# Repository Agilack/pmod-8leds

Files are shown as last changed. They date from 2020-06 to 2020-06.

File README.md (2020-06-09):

PMOD 8 Leds
===========

This project is a PMOD prototyping board with 8 LEDs.



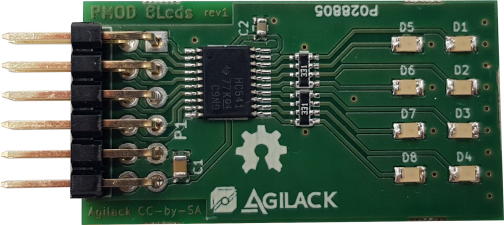
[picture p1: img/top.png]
top
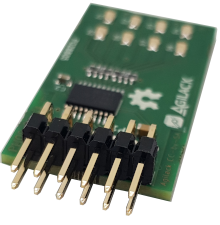
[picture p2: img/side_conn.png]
Side view
 | 
------------------- | -------------------------------

The board connector use a PMOD type 1A pinout. Each available GPIO is
connected to one LED with a component id that reflect signel id (LED D1 is
mapped to signal GPIO1, D2 for GPIO2 ...)
To avoid driving too much current from host ios, a buffer is placed between
connector and LEDs. This buffer add a small latency (~5ns) and limit the
switching frequency to fwe dozen MHz but this seem to be acceptable for
LEDs ;)

<p align="center">
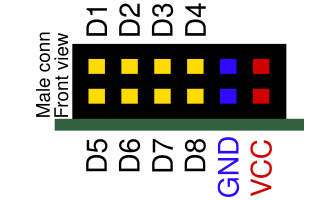
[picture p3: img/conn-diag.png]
Connector diagram

</p>

Designed with Kicad
-------------------
This board has been designed using Kicad 5.0.2
For a better compatibility and a simplified distribution of this project,
all schematics components are available into a custom project library. It's
the same for board footprints that have been saved into a cutom library. For
3D models, default kicad parts are used (and some display errors can occurs)

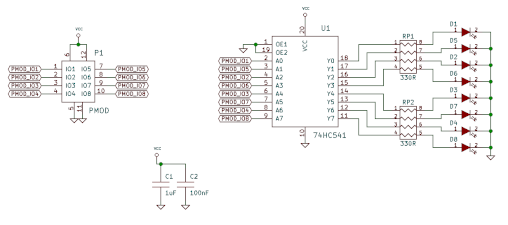
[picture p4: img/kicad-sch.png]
SCH
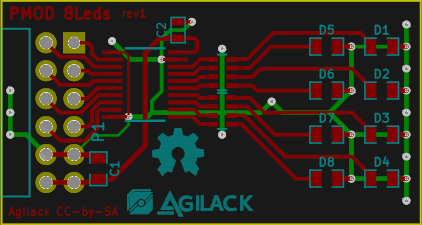
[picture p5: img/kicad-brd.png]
BRD
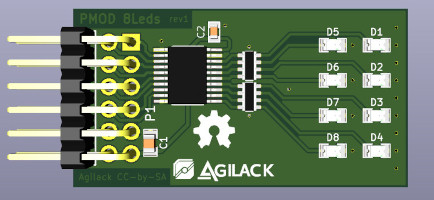
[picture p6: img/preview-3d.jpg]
3D Preview
 |  | 
------------------------- | ------------------------- | ---------------------------------

License
-------

This project is licensed under a [Creative Commons Attribution-ShareAlike 4.0 International License](http://creativecommons.org/licenses/by-sa/4.0/).



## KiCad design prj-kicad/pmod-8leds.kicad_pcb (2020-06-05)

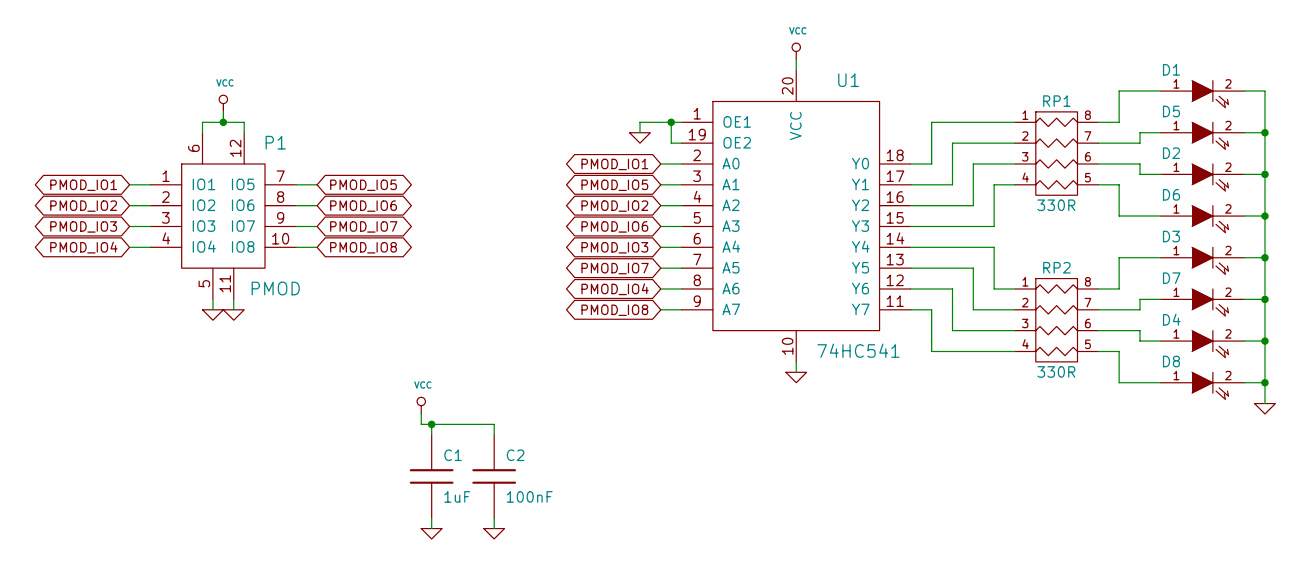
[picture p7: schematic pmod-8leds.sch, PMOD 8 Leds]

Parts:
C1: 1uF; SMD0805
C2: 100nF; SMD0603
D1, D2, D3, D4, D5, D6, D7, D8: LED; SMD0805
P1: PMOD; CONN_PMOD-Male
RP1, RP2: 330R; R_4x0603
U1: 74HC541; TSSOP20

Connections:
GND: C1.2, C2.2, D1.2 (K), D2.2 (K), D3.2 (K), D4.2 (K), D5.2 (K), D6.2 (K), D7.2 (K), D8.2 (K), P1.5, P1.11, U1.1 (OE1), U1.10, U1.19 (OE2)
unnamed: D1.1 (A), RP1.8 (R1)
unnamed: D2.1 (A), RP1.6 (R3)
unnamed: D3.1 (A), RP2.8 (R1)
unnamed: D4.1 (A), RP2.6 (R3)
unnamed: D5.1 (A), RP1.7 (R2)
unnamed: D6.1 (A), RP1.5 (R4)
unnamed: D7.1 (A), RP2.7 (R2)
unnamed: D8.1 (A), RP2.5 (R4)
unnamed: RP1.1, U1.18 (Y0)
unnamed: RP1.2, U1.17 (Y1)
unnamed: RP1.3, U1.16 (Y2)
unnamed: RP1.4, U1.15 (Y3)
unnamed: RP2.1, U1.14 (Y4)
unnamed: RP2.2, U1.13 (Y5)
unnamed: RP2.3, U1.12 (Y6)
unnamed: RP2.4, U1.11 (Y7)
PMOD_IO1: P1.1 (IO1), U1.2 (A0)
PMOD_IO2: P1.2 (IO2), U1.4 (A2)
PMOD_IO3: P1.3 (IO3), U1.6 (A4)
PMOD_IO4: P1.4 (IO4), U1.8 (A6)
PMOD_IO5: P1.7 (IO5), U1.3 (A1)
PMOD_IO6: P1.8 (IO6), U1.5 (A3)
PMOD_IO7: P1.9 (IO7), U1.7 (A5)
PMOD_IO8: P1.10 (IO8), U1.9 (A7)
VCC: C1.1, C2.1, P1.6, P1.12, U1.20 (VCC)

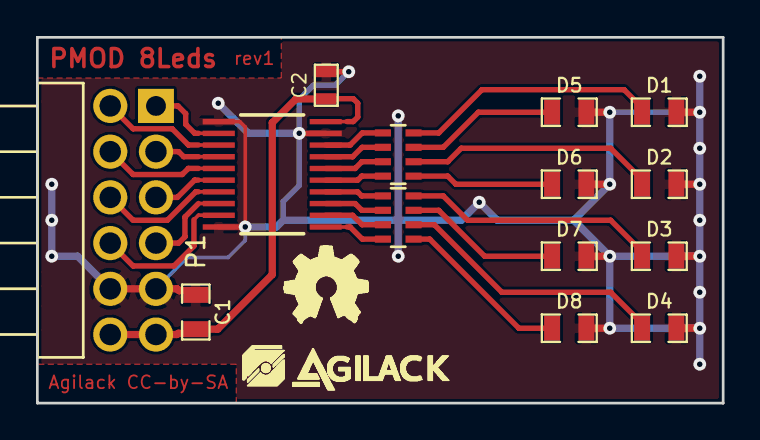
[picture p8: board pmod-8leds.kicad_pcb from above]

Board: 2 copper layers, 38.1 x 20.3 mm, 16 parts (0 on the bottom side), 26 nets.

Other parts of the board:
agilack-11.5: 450px; logo-agilack-11.5
ohw_logo: VAL**; logo-ohw

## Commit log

2020-06-04 = ADD: Create schematic and pcb routing
    [pmod-8leds.kicad_pcb, pmod-8leds.sch]
2020-06-05 = ADD: Create production files (gerber)
    [pmod-8leds-B.Cu.gbr, pmod-8leds-B.Mask.gbr, pmod-8leds-B.Paste.gbr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]
2020-06-09 = UPD: Insert pictures of real board and update readme file

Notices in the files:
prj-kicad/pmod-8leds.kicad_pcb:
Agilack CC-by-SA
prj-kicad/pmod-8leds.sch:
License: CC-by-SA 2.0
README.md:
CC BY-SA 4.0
